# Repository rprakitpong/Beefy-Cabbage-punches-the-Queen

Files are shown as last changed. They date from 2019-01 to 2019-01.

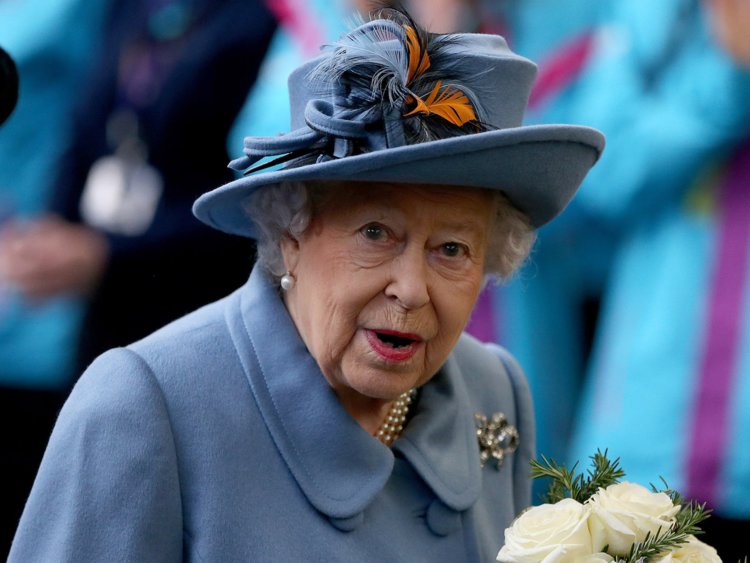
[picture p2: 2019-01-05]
step2 - paint.net/queen of england reference.jpg

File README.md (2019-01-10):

## Beefy Cabbage punches the Queen
A automata side project from a reddit meme from r/me_irl

# !!!DISCLAIMER!!!
## This project is a joke. I mean no harm to any subject involved in this automata. 
## Please do not take this to mean anything other than a toy.

### 4 main steps:

#### 1. Mechanical design in Solidworks:
- The cabbage's arm punches the Queen, so it needs rotation from gears and shaft
- The Queen's head bounces up when punched, so it needs a cam rotated by gears
- The two motion needs to be in sync, so two spur gears connect them
- All key dimensions abstracted into equations.txt config file (Pragmatic Programmer yeeeeee)

#### 2. Get vector files of Queen, muscular arm, and cabbage from Paint.net:
- I would've used Illustrator for this if I could get it legally
- Rescale images to appropriate size according to Solidworks models
- You can extrude images into solids in Blender but you need to make a vector outline first

#### 3. Assembly in Blender:
- Extrude the 3 images into flat solids and place them according to shaft and cam positions
- Adjust any models from Solidworks to fit the new stuff
- Make sure everything is assembleable in real life
- Export the files appropriately

#### 4. 3D Print the files and play with it:
- 3D print the stls
- 2D print the corresponding images of the Queen, muscular arm, and cabbage
- Glue images to flat solids and assemble all parts

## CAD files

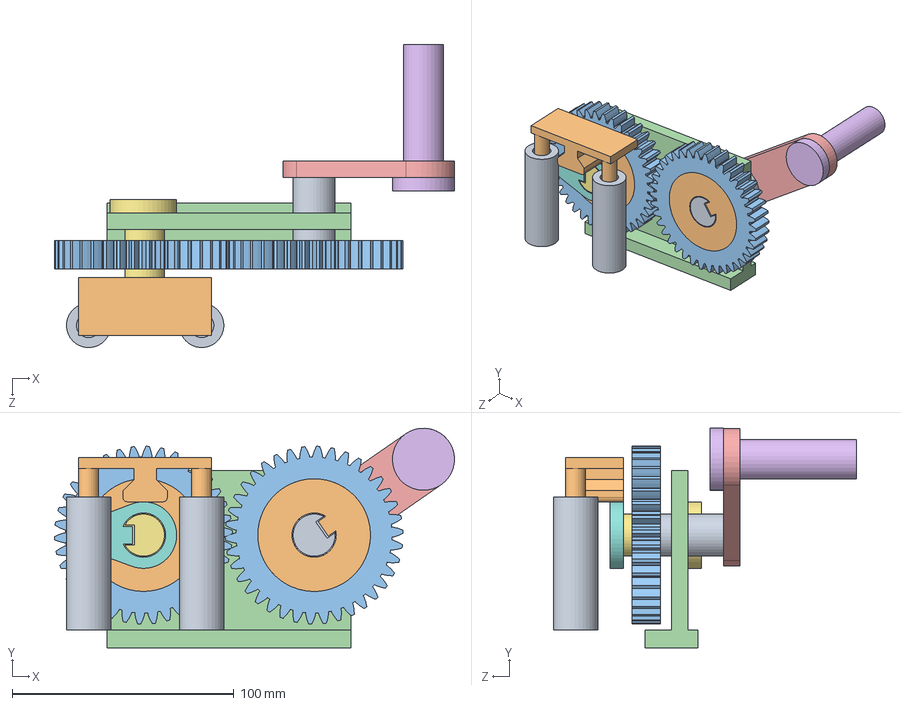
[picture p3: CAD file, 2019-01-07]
step1 - sldr/Assem.SLDASM
180.4 x 99.0 x 136.7 mm
crankShaft
gear insert x 2
Gear Design Tutorial x 2
panelStand
turningHandleConnector
turningHandle
crackArmShaft
crackArmCam
camFollowerAligningShaftHolder x 2
camFollowerWithAligningShaft

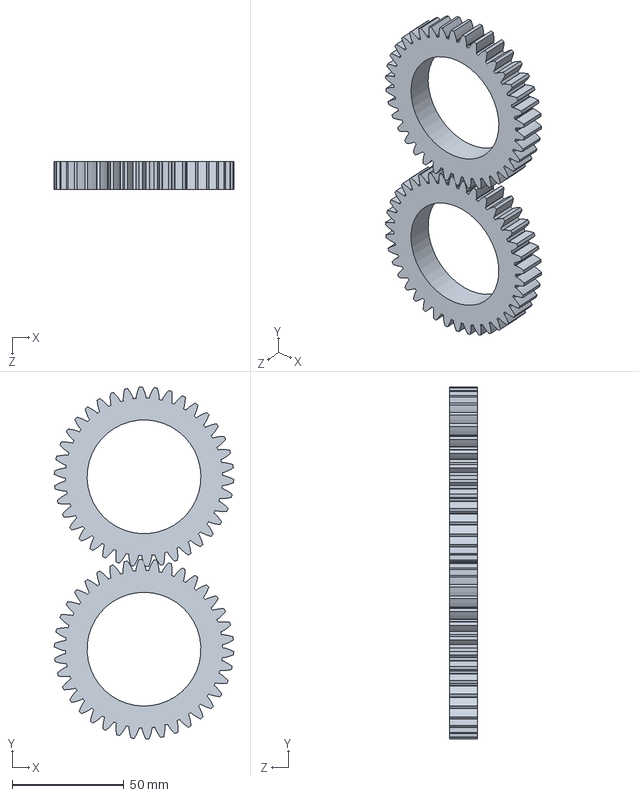
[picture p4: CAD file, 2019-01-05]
step1 - sldr/Gear System.SLDASM
80.2 x 157.2 x 12.7 mm
Gear Design Tutorial x 2

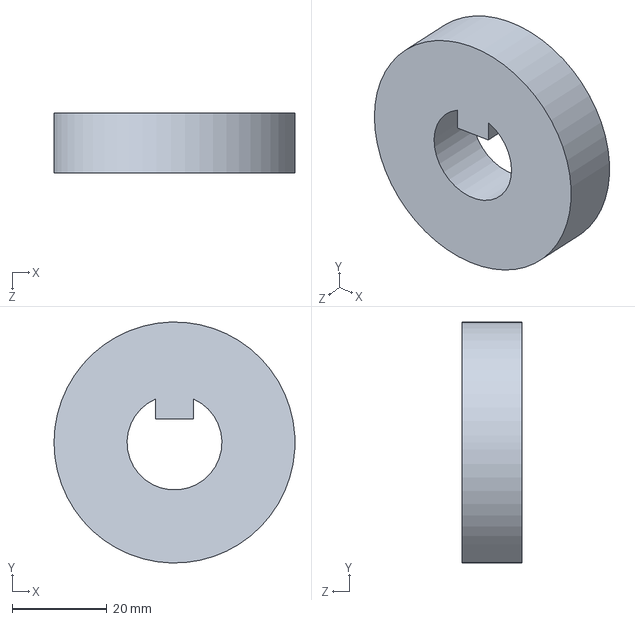
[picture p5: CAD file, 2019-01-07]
step1 - sldr/gear insert.SLDPRT
50.8 x 50.8 x 12.7 mm

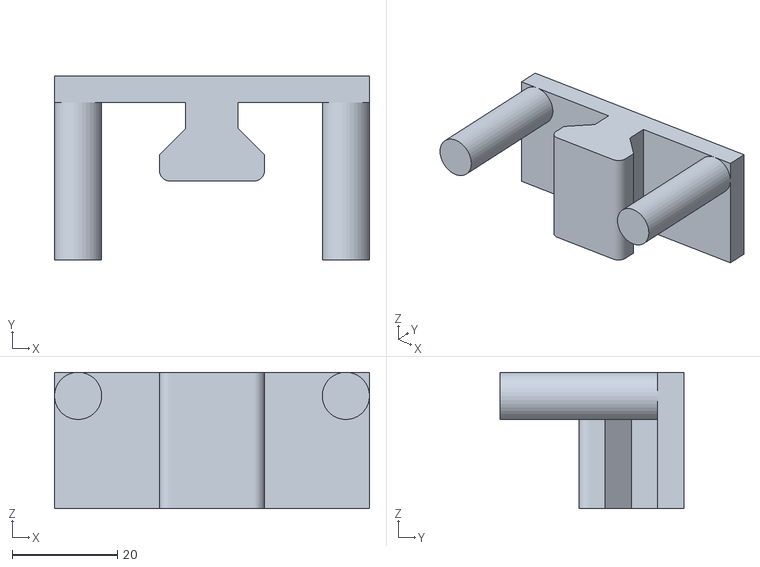
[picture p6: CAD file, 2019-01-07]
step3 - blender/FilesFromSldr - camFollowerWithAligningShaft-1.STL
60.0 x 35.0 x 26.0

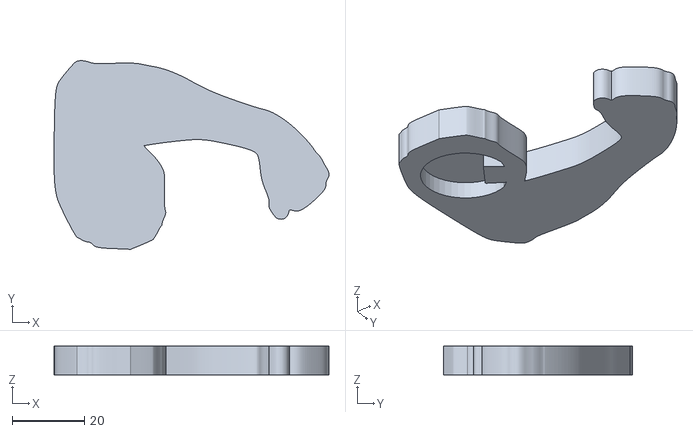
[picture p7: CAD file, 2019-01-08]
step4 - 3DP final files/muscularArm-1.stl
76.2 x 52.3 x 8.00

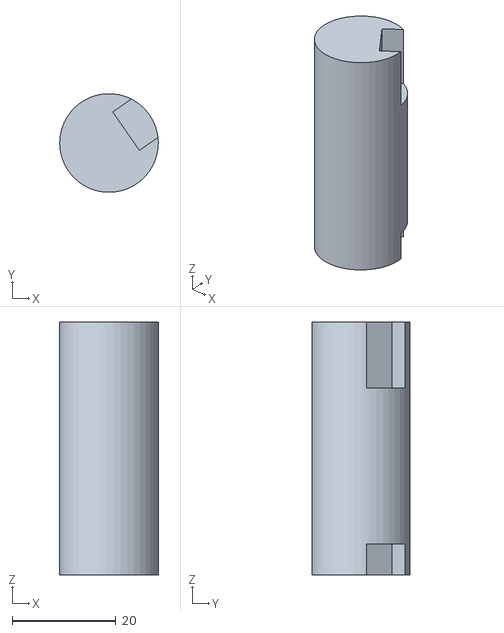
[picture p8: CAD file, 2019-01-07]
step3 - blender/FilesFromSldr - crankShaft-1.STL
19.0 x 19.0 x 48.7

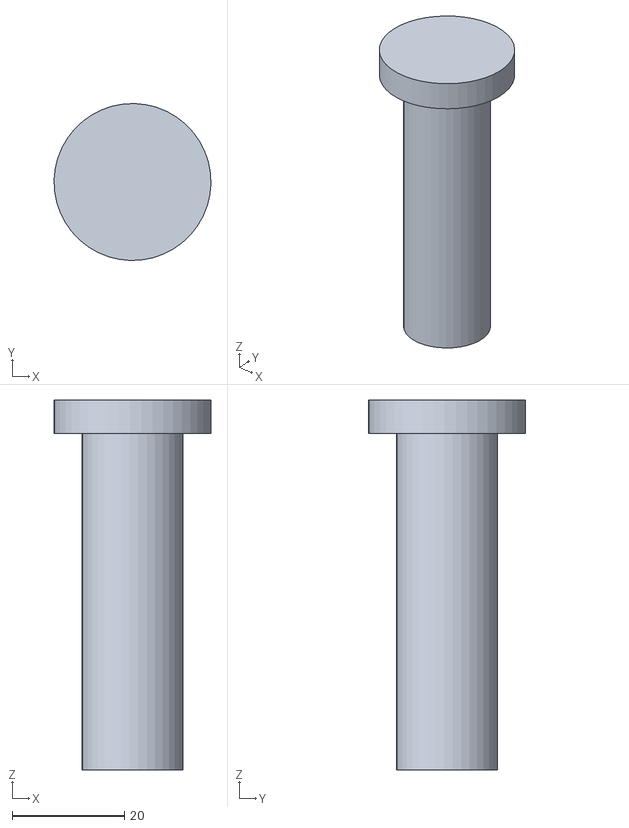
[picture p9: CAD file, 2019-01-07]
step3 - blender/FilesFromSldr - turningHandle-1.STL
28.0 x 28.0 x 66.0

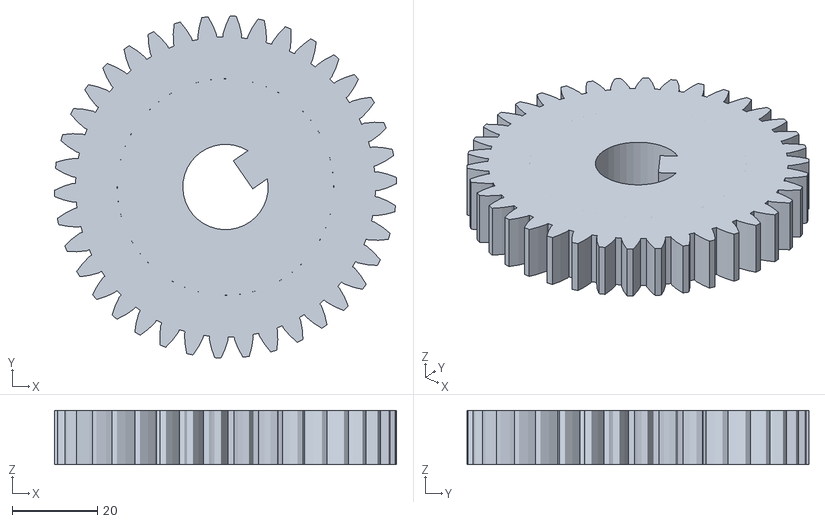
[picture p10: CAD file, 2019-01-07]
step4 - 3DP final files/gearWithInsert-2.stl
80.2 x 80.2 x 12.7

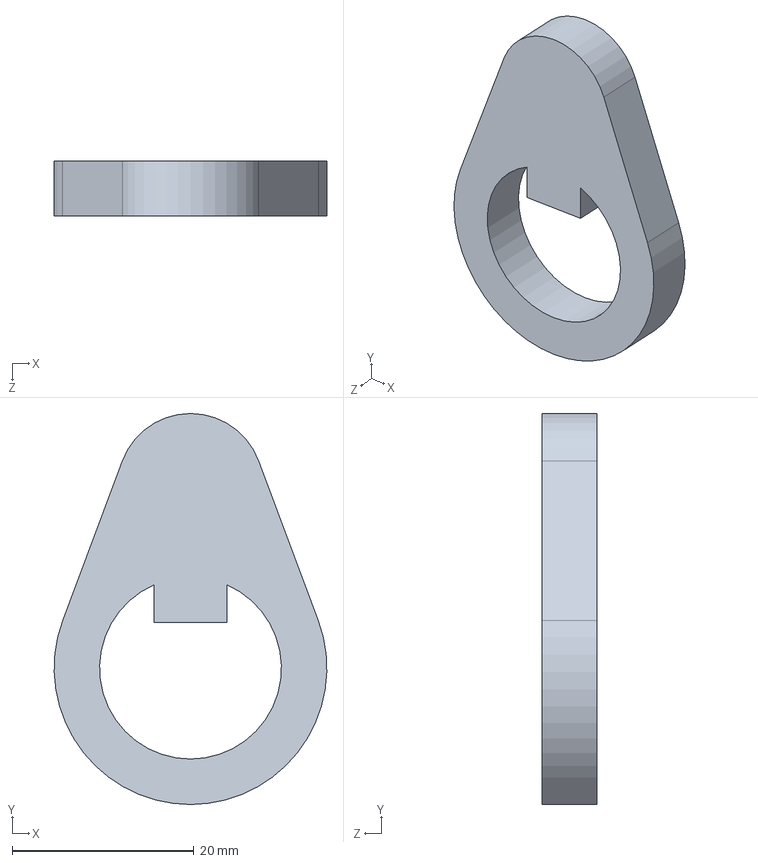
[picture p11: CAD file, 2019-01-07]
step1 - sldr/crackArmCam.SLDPRT
30.0 x 43.0 x 6.00 mm

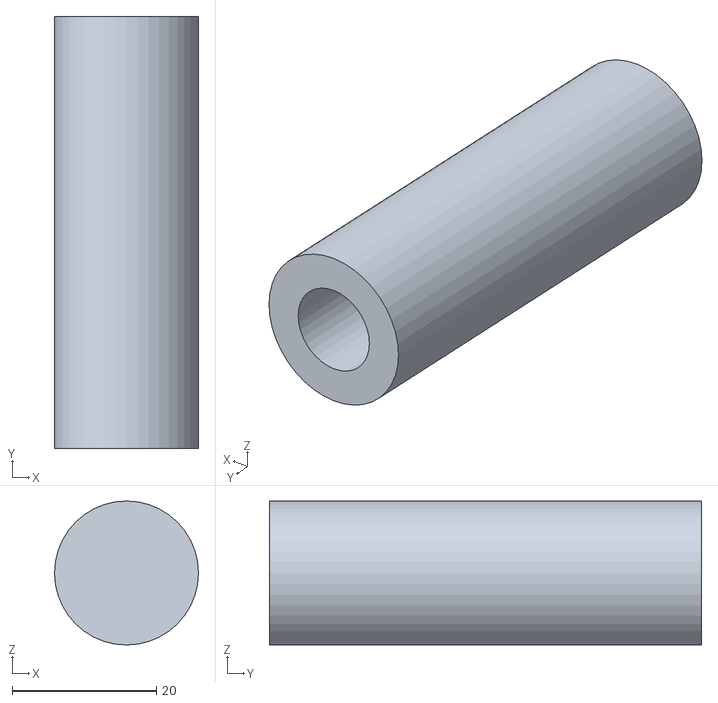
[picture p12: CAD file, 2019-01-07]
step3 - blender/FilesFromSldr - camFollowerAligningShaftHolder-3.STL
20.0 x 60.0 x 20.0

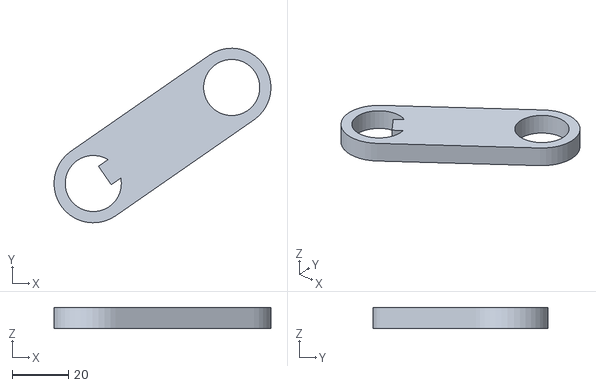
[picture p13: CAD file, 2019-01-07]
step4 - 3DP final files/turningHandleConnector-1.STL
77.3 x 62.2 x 7.50

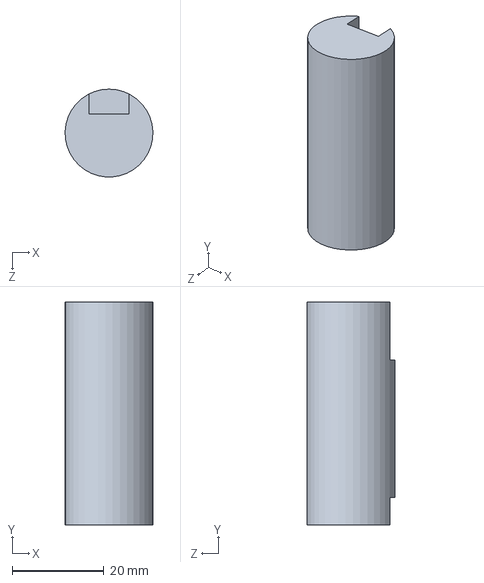
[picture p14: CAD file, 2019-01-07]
step1 - sldr/crankShaft.SLDPRT
19.2 x 48.7 x 19.2 mm

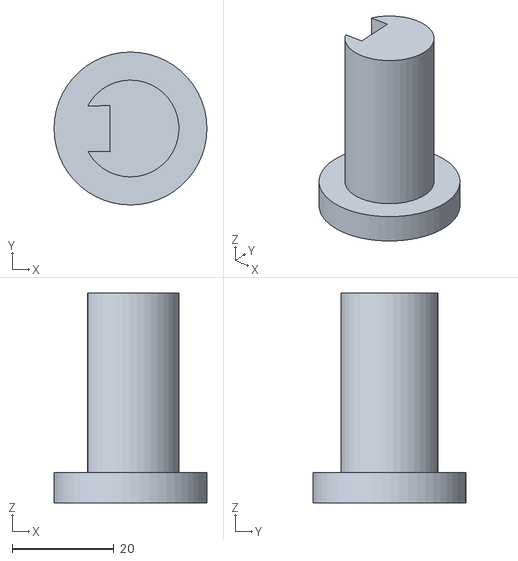
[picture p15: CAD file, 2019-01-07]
step3 - blender/FilesFromSldr - crackArmShaft-1.STL
30.0 x 30.0 x 41.2

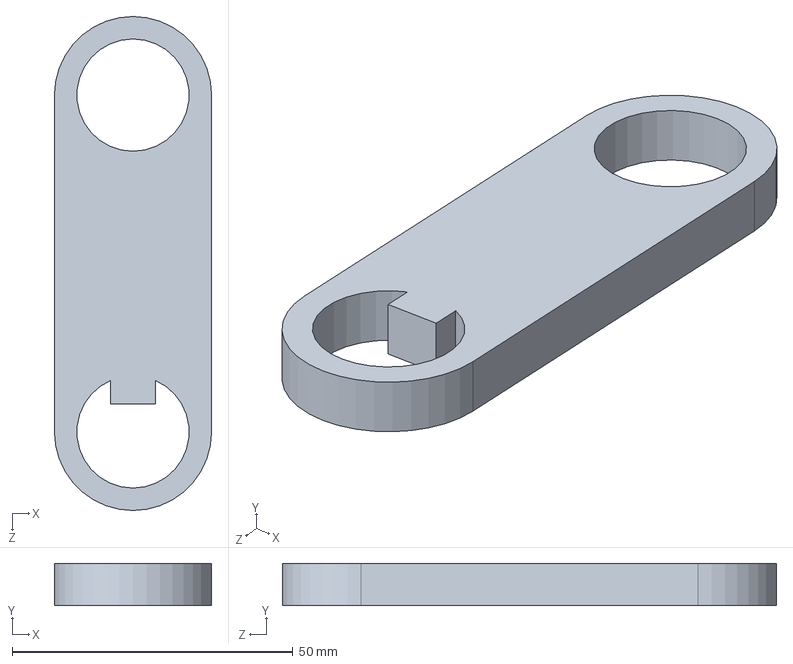
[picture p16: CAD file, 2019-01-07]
step1 - sldr/turningHandleConnector.SLDPRT
28.0 x 7.50 x 88.0 mm

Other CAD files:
step1 - sldr/camFollowerWithAligningShaft.SLDPRT
step4 - 3DP final files/camFollowerWithAligningShaft-1.STL
step4 - 3DP final files/turningHandle-1.STL
step3 - blender/FilesFromSldr - camFollowerAligningShaftHolder-1.STL
step1 - sldr/Gear Design Tutorial.SLDPRT
step1 - sldr/camFollowerAligningShaftHolder.SLDPRT
step1 - sldr/crackArmShaft.SLDPRT
step1 - sldr/panelStand.SLDPRT
step1 - sldr/turningHandle.SLDPRT
step3 - blender/FilesFromSldr - Gear System-1 Gear Design Tutorial-1.STL
step3 - blender/FilesFromSldr - Gear System-1 Gear Design Tutorial-2.STL
step3 - blender/FilesFromSldr - gear insert-1.STL
step3 - blender/FilesFromSldr - gear insert-2.STL
step3 - blender/FilesFromSldr - panelStand-1.STL
step3 - blender/assem.blend
step4 - 3DP final files/cabbageWithStand-1.stl
step4 - 3DP final files/camFollowerAligningShaftHolder-2.STL
step4 - 3DP final files/crackArmCam-1.STL
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

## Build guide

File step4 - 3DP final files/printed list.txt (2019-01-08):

cabWStand - y
camFolHolder 
camFol - y
crackArmCam - y
crackArmShaft - y
gear - y
mArm - y
mArmShaft - y 
queenBod - y
queenHead - y
standPanel - y
tHandle - y 
tHandleConnector - y

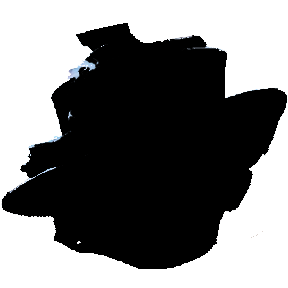
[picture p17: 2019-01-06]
step2 - paint.net/queen-headonly-nobackgournd-black-3by3in.png

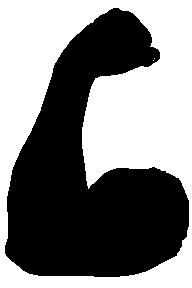
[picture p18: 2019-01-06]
step2 - paint.net/muscular-arm-nobackgournd-black-3by2in.png

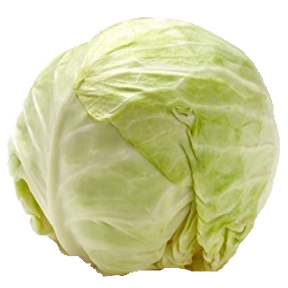
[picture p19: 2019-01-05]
step2 - paint.net/cabbage-nobackground-2by2in.png

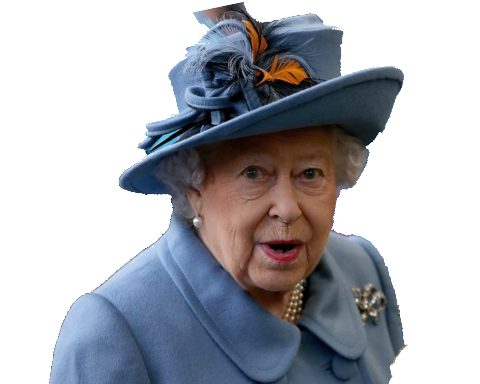
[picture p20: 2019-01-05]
step2 - paint.net/queen-withhead-nobackground-5by4in.png

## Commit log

2019-01-06 finished step2 and halfway through step3
    -use https://image.online-convert.com/convert-to-svg to get svg from png
    [Assem.SLDASM, FilesFromSldr - Gear System-1 Gear Design Tutorial-1.STL, FilesFromSldr - Gear System-1 Gear Design Tutorial-2.STL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]
2019-01-06 finished step3 and exported all files for step4
    [armWithGearShaft-1.stl, assem.blend, cabbageWithStand-1.stl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]
2019-01-06 minor fixes
    - separated musculararm into arm part and shaft part to make gear insertable
    - did the math to make motion of arm and the queen's head moving in sync
    [armWithGearShaft-1.stl, assem.blend, muscularArm-1.stl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]
2019-01-06 resaved blender assem
    for good luck
    [assem.blend]
2019-01-06 redesign cam follower
    - redesign and re-export cam follower to make it print without support in an orientation that takes up less bed space
    [Assem.SLDASM, FilesFromSldr - camFollowerWithAligningShaft-1.STL, assem.blend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]
2019-01-06 changed clearance between parts
    - printed some stuff out and it was a bit tight
    - increased clearance from .8mm to 1mm, and added a multipllier where the fit has to be a sliding fit
    - still have to reexport and reimport into blender assembly
    [Assem.SLDASM, camFollowerAligningShaftHolder.SLDPRT, camFollowerWithAligningShaft.SLDPRT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]
2019-01-07 Reimported new models to blender assem
    - Also reexported new final models for printing
    - made a .txt list in step4 folder to keep track for what's already been printed
    [Assem.SLDASM, FilesFromSldr - camFollowerAligningShaftHolder-1.STL, FilesFromSldr - camFollowerAligningShaftHolder-3.STL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]
2019-01-08 Better fit for arm shaft holder
    - initially used make a scale up version of the shaft and do a bool diff on the arm to make a hole for the shaft to go into
    - now use offset (alt-s) to make the bool diff instead. offset gives a linear, equal amount of gap to all edges, while scaling gives uneven amount of gap.
    - this should make things fit much better.
    [assem.blend, muscularArm-1.stl]
2019-01-10 pausing on the project for now
    - 3d printed most of the parts, and the main issues are:
    -since the sliding rods of the cam causes moment on cam follower instead of linear motion, because sliding rod holder didnt constain motion of sliding rods enough (too much clearance)
    - need additional gear shaft holder. both were tilting down (again too much clearance)
    - print spacers so gears and cam stay in place within the shaft
    [assem.blend]
